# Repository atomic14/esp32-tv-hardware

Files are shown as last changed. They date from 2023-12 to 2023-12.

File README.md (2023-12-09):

# WIP - ESP32-TV Hardware Files

This is Work In Progress - I'm still working on this.

This repo contains/will contain the hardware design files for the ESP32-TV project.

## Schematic

You can either open this up in KiCad, or there's a PDF [here](./images/micro-esp32-s3.pdf).

Schematic

## PCB

Open this up in KiCad to export the Gerber files.

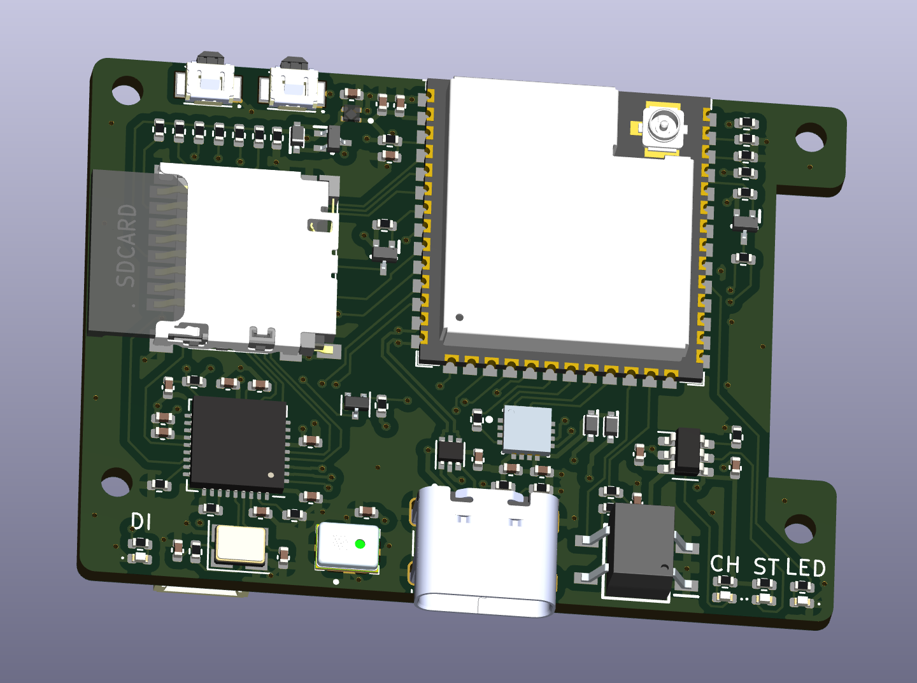
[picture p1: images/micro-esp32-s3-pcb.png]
PCB


## What's this all about?

More details to follow...

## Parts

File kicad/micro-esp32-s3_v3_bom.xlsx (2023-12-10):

Item # | *Designator | *Qty | Manufacturer | *Mfg Part # | Description / Value | *Package/Footprint | Mounting Type | Your Instructions / Notes
1 | R31,R30,R29,R28,R27,R26,R20,R13,R24,R19,R22,R23,R21 | 13 | KOA Speer | SG73P1EWTTP1002F | 10K | R_0402_1005Metric | SMD
2 | S2,S1 | 2 | Omron Electronics | B3U-3000P | B3U-3000P | SW_B3U-3000P | SMD
3 | C1,C20,C8,C10,C13,C11,C12,C21 | 8 | YAGEO | CC0402KRX5R6BB104 | 100nF | C_0402_1005Metric | SMD
4 | R3,R7,R4,R2 | 4 | RALEC | RTT02512JTH | 5.1K | R_0402_1005Metric | SMD
5 | U8 | 1 | OLEWOLFF | OWMMOD-403010A-S261F | OWMMOD-403010A-S261F | OWMMOD-403010A-S261F | SMD | NOTE - this is the top ported version - OWMMOD-403010A-S261F - https://mm.digikey.com/Volume0/opasdata/d220001/medias/docus/5395/OWMMOD-403010A-S261F.pdf
6 | C17,C19,C2,C16,C4 | 5 | CCTC | TCC0402X5R105K100AT | 1uF | C_0402_1005Metric | SMD
7 | U6 | 1 | TECH PUBLIC | USBLC6-2P6 | USBLC6-2P6 | SOT-666-6 | SMD
8 | D7,D6,D1 | 3 | Infineon | BAS 52-02V H6327 | BAS5202VH6327XTSA1 | SODFL1608X59N | SMD
9 | C5,C6,C18,C7 | 4 | SAMSUNG | CL05A106MP5NUNC | 10uF | C_0402_1005Metric | SMD
10 | R15 | 1 | YAGEO | AF0402FR-07634KL | 634K | R_0402_1005Metric | SMD
11 | IC1 | 1 | Everlight | IRM-H638T/TR2 | IRM-H638T/TR2 | SOP254P700X405-4N | SMD
12 | Q1,Q3,Q2 | 3 | onsemi | NTA4151PT1G | NTA4151PT1G | SOT50P160X90-3N | SMD
13 | U1 | 1 | onsemi | NCP167BMX330TBG | NCP167BMX330TBG | VREG_NCP167BMX330TBG | SMD
14 | R1,R14,R17 | 3 | KOA Speer | SG73P1EWTTP1003F | 100K | R_0402_1005Metric | SMD
15 | D5 | 1 | Everlight Elec | 16-213UYC/S530-A2/TR8 | YELLOW LED | LED_0402_1005Metric | SMD | Any 0402 Yellow LED
16 | R18 | 1 | KOA Speer | RK73H1ERTTP39R0F | 39 | R_0402_1005Metric | SMD
17 | R12,R10,R25 | 3 | KOA Speer | SG73P1EWTTP1202F | 12K | R_0402_1005Metric | SMD
18 | U4 | 1 | TOPPOWER | TP4057-42-SOT26-R | TP4057 | SOT-23-6 | SMD
19 | U2 | 1 | Espressif Systems | ESP32-S3-WROOM-1U-N8R8 | ESP32-S3-WROOM-1 | ESP32-S3-WROOM-1U | SMD
20 | Q4 | 1 | TECH PUBLIC | TPNTA4153NT1G | TPNTA4153NT1G | SOT-523-3 | SMD
21 | C3 | 1 | muRata | GRM155R60J226ME11D | 22uF | C_0402_1005Metric | SMD
22 | C14,C15 | 2 | Kyocera AVX | 0402ZK180FBWTR | 18pF | C_0402_1005Metric | SMD
23 | U5 | 1 | Microchip | USB2240-AEZG-06 | USB2240 | QFN-36-EP(6x6) | SMD
24 | R5,R9,R6,R8,R11 | 5 | KOA Speer | SG73P1EWTTP221G | 220R | R_0402_1005Metric | SMD
25 | Y1 | 1 | JWT | CF4024M00012 | Crystal_GND24 (24MHz) | Crystal_SMD_3225-4Pin_3.2x2.5mm | SMD
26 | C9 | 1 | Samsung Electro-Mechanics | CL05A475MP5NRNC | 4.7uF | C_0402_1005Metric | SMD
27 | J3 | 1 | Hirose | DM3D-SF | DM3D-SF | DM3DSF | SMD
28 | D2 | 1 | Everlight Elec | 16-213/R6C-AQ2R2B/3T | RED LED | LED_0402_1005Metric | SMD | Any 0402 Red LED
29 | D3 | 1 | Everlight Elec | 16-213/BHC-AN1P2/3T | BLUE LED | LED_0402_1005Metric | SMD | Any 0402 Blue LED
30 | R16 | 1 | KOA Speer | SG73P1EWTTP1004F | 1M | R_0402_1005Metric | SMD
31 | U3 | 1 | MAXIM | MAX98357AETE+T | MAX98357AETE+T | TQFN-16_L3.0-W3.0-P0.50-BL-EP1.5 | SMD
32 | J1 | 1 | 韩国韩荣 | TYPE-C-31-M-12 | TYPE-C-31-M-12 | USB-C_SMD-TYPE-C-31-M-12 | SMD
33 | D3 | 1 | Everlight Elec | 16-213/GHC-YR1S1/3T | GREEN LED | LED_0402_1005Metric | SMD | Any 0402 Green LED
34 | SPK1,BAT1 | 2 | JST | S2B-ZR-SM4A-TF | S2B-ZR-SM4A-TF_LF__SN_ | S2B-ZR-SM4A-TF | SMD
35 | QWIIC1 | 1 | JST | SM04B-SRSS-TB | SM04B-SRSS-TB_LF__SN_ | SM04B-SRSS-TB | SMD

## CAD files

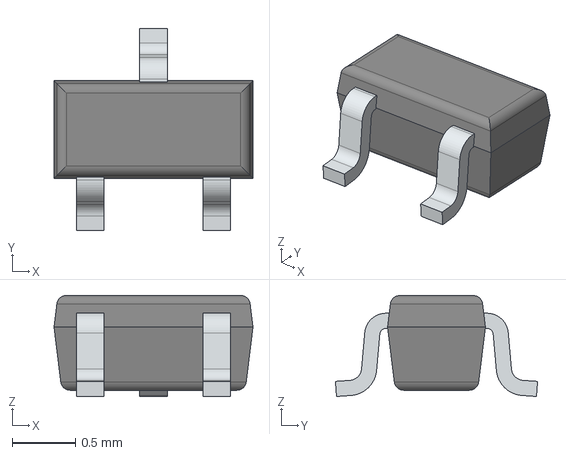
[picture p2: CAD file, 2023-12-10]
kicad/3dmodels/SOT-523-STP.stp
1.58 x 1.60 x 0.799 mm
LF
CPD

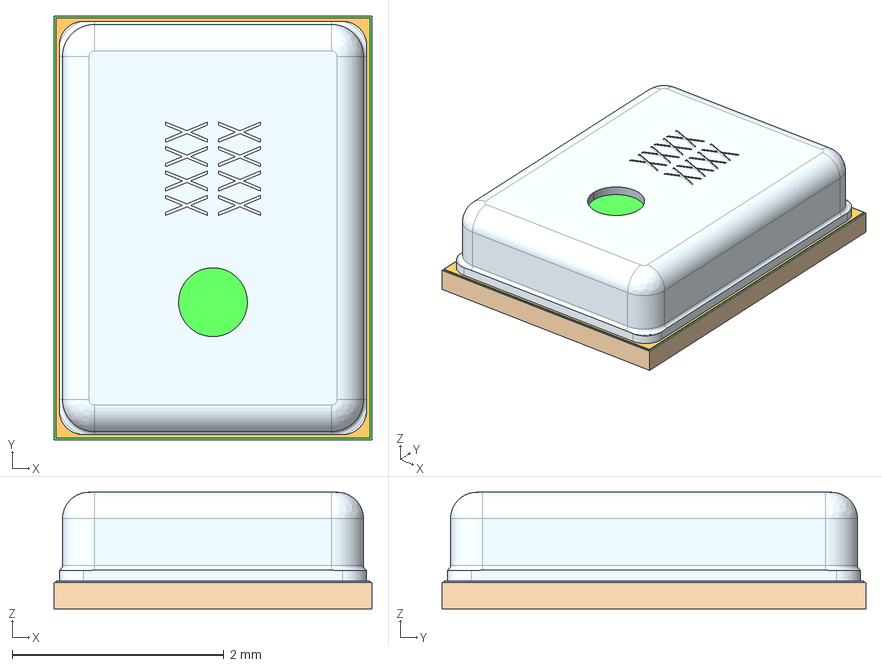
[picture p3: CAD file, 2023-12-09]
kicad/OWMMOD_403010A_S261F/OWMMOD-403010A-S261F.step
3.00 x 4.00 x 1.10 mm

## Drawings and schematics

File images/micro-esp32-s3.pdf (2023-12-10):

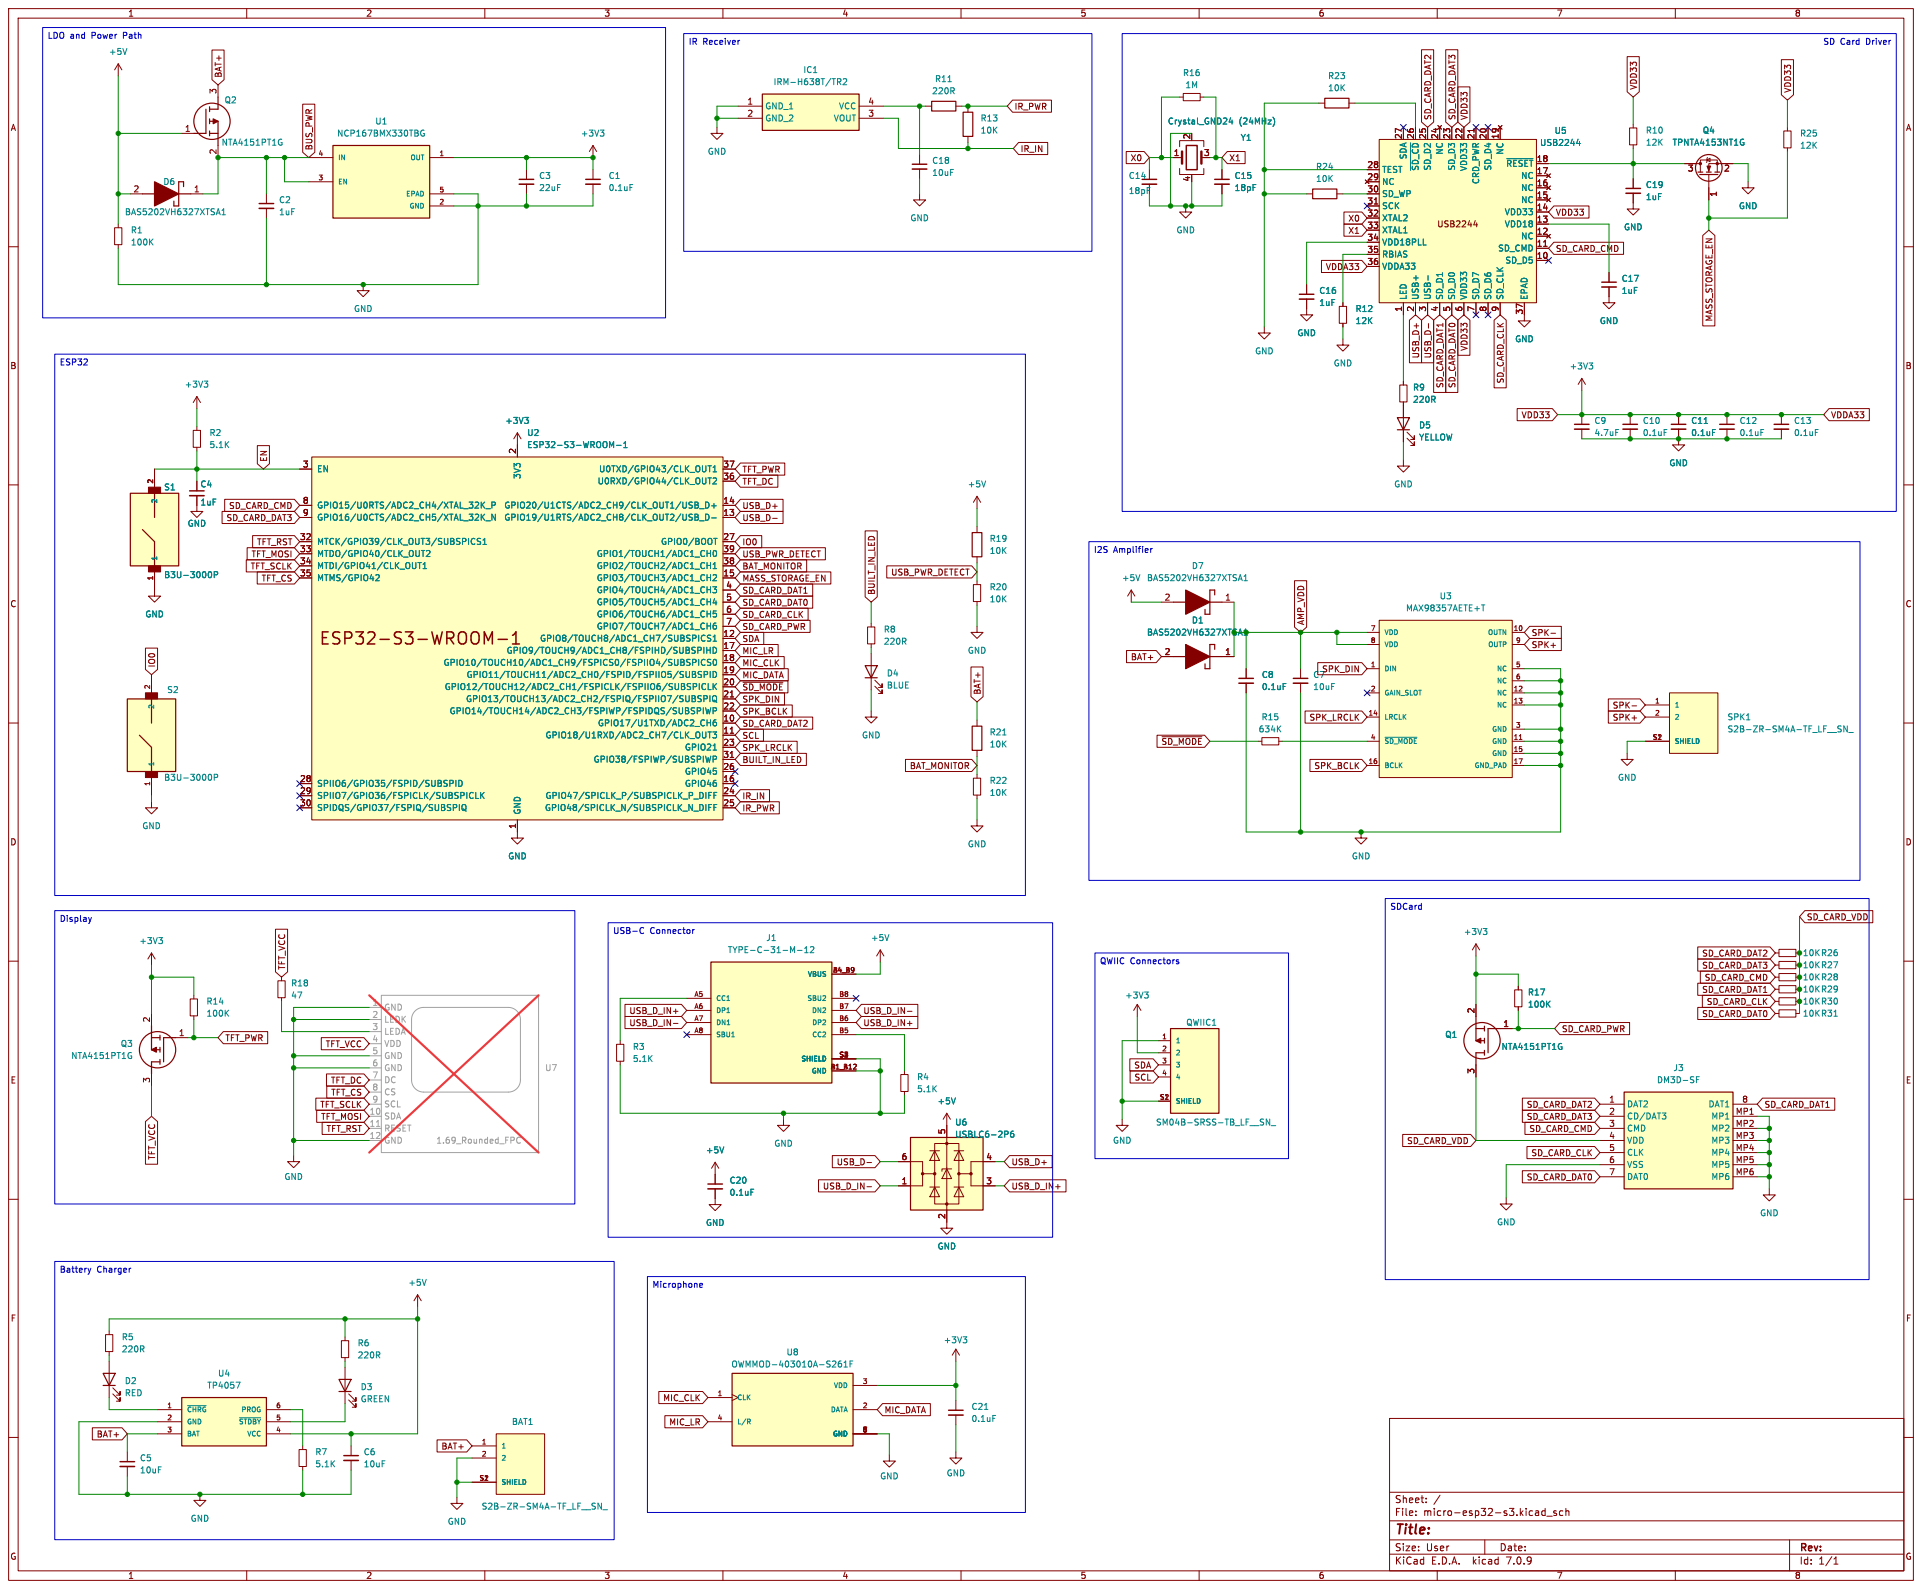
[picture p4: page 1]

LDO and Power Path

2 SD_D4 20 CRD_PWR 21 VDD33 22 SD_D3 23 NC 24 SD_D2 25 ~{SD_CD} 26 SDA 27 TEST 28 NC 29 USB- 3 SD_WP 30 SCK 31 XTAL2 32 XTAL1 33 VDD18PLL 34 RBIAS 35 VDDA33 36 SD_D1

1 SD_D5 10 SD_CMD 11 NC 12 VDD18 13 VDD33 14 NC 15 NC 16 NC 17 ~{RESET} 18 NC 19 USB+

2 GPIO12/TOUCH12/ADC2_CH1/FSPICLK/FSPIIO6/SUBSPICLK 20 GPIO13/TOUCH13/ADC2_CH2/FSPIQ/FSPIIO7/SUBSPIQ 21 GPIO14/TOUCH14/ADC2_CH3/FSPIWP/FSPIDQS/SUBSPIWP 22 GPIO21 23 GPIO47/SPICLK_P/SUBSPICLK_P_DIFF 24 GPIO48/SPICLK_N/SUBSPICLK_N_DIFF 25 GPIO45 26 GPIO0/BOOT 27 SPIIO6/GPIO35/FSPID/SUBSPID 28 SPIIO7/GPIO36/FSPICLK/SUBSPICLK 29 EN 3 SPIDQS/GPIO37/FSPIQ/SUBSPIQ 30 GPIO38/FSPIWP/SUBSPIWP 31 MTCK/GPIO39/CLK_OUT3/SUBSPICS1 32 MTDO/GPIO40/CLK_OUT2 33 MTDI/GPIO41/CLK_OUT1 34 MTMS/GPIO42 35 U0RXD/GPIO44/CLK_OUT2 36 U0TXD/GPIO43/CLK_OUT1 37 GPIO2/TOUCH2/ADC1_CH1 38 GPIO1/TOUCH1/ADC1_CH0 39 GPIO4/TOUCH4/ADC1_CH3 4 GPIO5/TOUCH5/ADC1_CH4 5 GPIO6/TOUCH6/ADC1_CH5 6 GPIO7/TOUCH7/ADC1_CH6 7 GPIO15/U0RTS/ADC2_CH4/XTAL_32K_P 8 GPIO16/U0CTS/ADC2_CH5/XTAL_32K_N 9 +3V3 S1B3U-3000P

2 GPIO12/TOUCH12/ADC2_CH1/FSPICLK/FSPIIO6/SUBSPICLK 20 GPIO13/TOUCH13/ADC2_CH2/FSPIQ/FSPIIO7/SUBSPIQ 21 GPIO14/TOUCH14/ADC2_CH3/FSPIWP/FSPIDQS/SUBSPIWP 22 GPIO21 23 GPIO47/SPICLK_P/SUBSPICLK_P_DIFF 24 GPIO48/SPICLK_N/SUBSPICLK_N_DIFF 25 GPIO45 26 GPIO0/BOOT 27 SPIIO6/GPIO35/FSPID/SUBSPID 28 SPIIO7/GPIO36/FSPICLK/SUBSPICLK 29 EN 3 SPIDQS/GPIO37/FSPIQ/SUBSPIQ 30 GPIO38/FSPIWP/SUBSPIWP 31 MTCK/GPIO39/CLK_OUT3/SUBSPICS1 32 MTDO/GPIO40/CLK_OUT2 33 MTDI/GPIO41/CLK_OUT1 34 MTMS/GPIO42 35 U0RXD/GPIO44/CLK_OUT2 36 U0TXD/GPIO43/CLK_OUT1 37 GPIO2/TOUCH2/ADC1_CH1 38 GPIO1/TOUCH1/ADC1_CH0 39 GPIO4/TOUCH4/ADC1_CH3 4 GPIO5/TOUCH5/ADC1_CH4 5 GPIO6/TOUCH6/ADC1_CH5 6 GPIO7/TOUCH7/ADC1_CH6 7 GPIO15/U0RTS/ADC2_CH4/XTAL_32K_P 8 GPIO16/U0CTS/ADC2_CH5/XTAL_32K_N 9 U2ESP32-S3-WROOM-1

1 GPIO17/U1TXD/ADC2_CH6 10 GPIO18/U1RXD/ADC2_CH7/CLK_OUT3 11 GPIO8/TOUCH8/ADC1_CH7/SUBSPICS1 12 GPIO19/U1RTS/ADC2_CH8/CLK_OUT2/USB_D- 13 GPIO20/U1CTS/ADC2_CH9/CLK_OUT1/USB_D+ 14 GPIO3/TOUCH3/ADC1_CH2 15 GPIO46 16 GPIO9/TOUCH9/ADC1_CH8/FSPIHD/SUBSPIHD 17 GPIO10/TOUCH10/ADC1_CH9/FSPICS0/FSPIIO4/SUBSPICS0 18 GPIO11/TOUCH11/ADC2_CH0/FSPID/FSPIIO5/SUBSPID 19 3V3

Id: 1/1 Title: File: micro-esp32-s3.kicad_sch Sheet: /

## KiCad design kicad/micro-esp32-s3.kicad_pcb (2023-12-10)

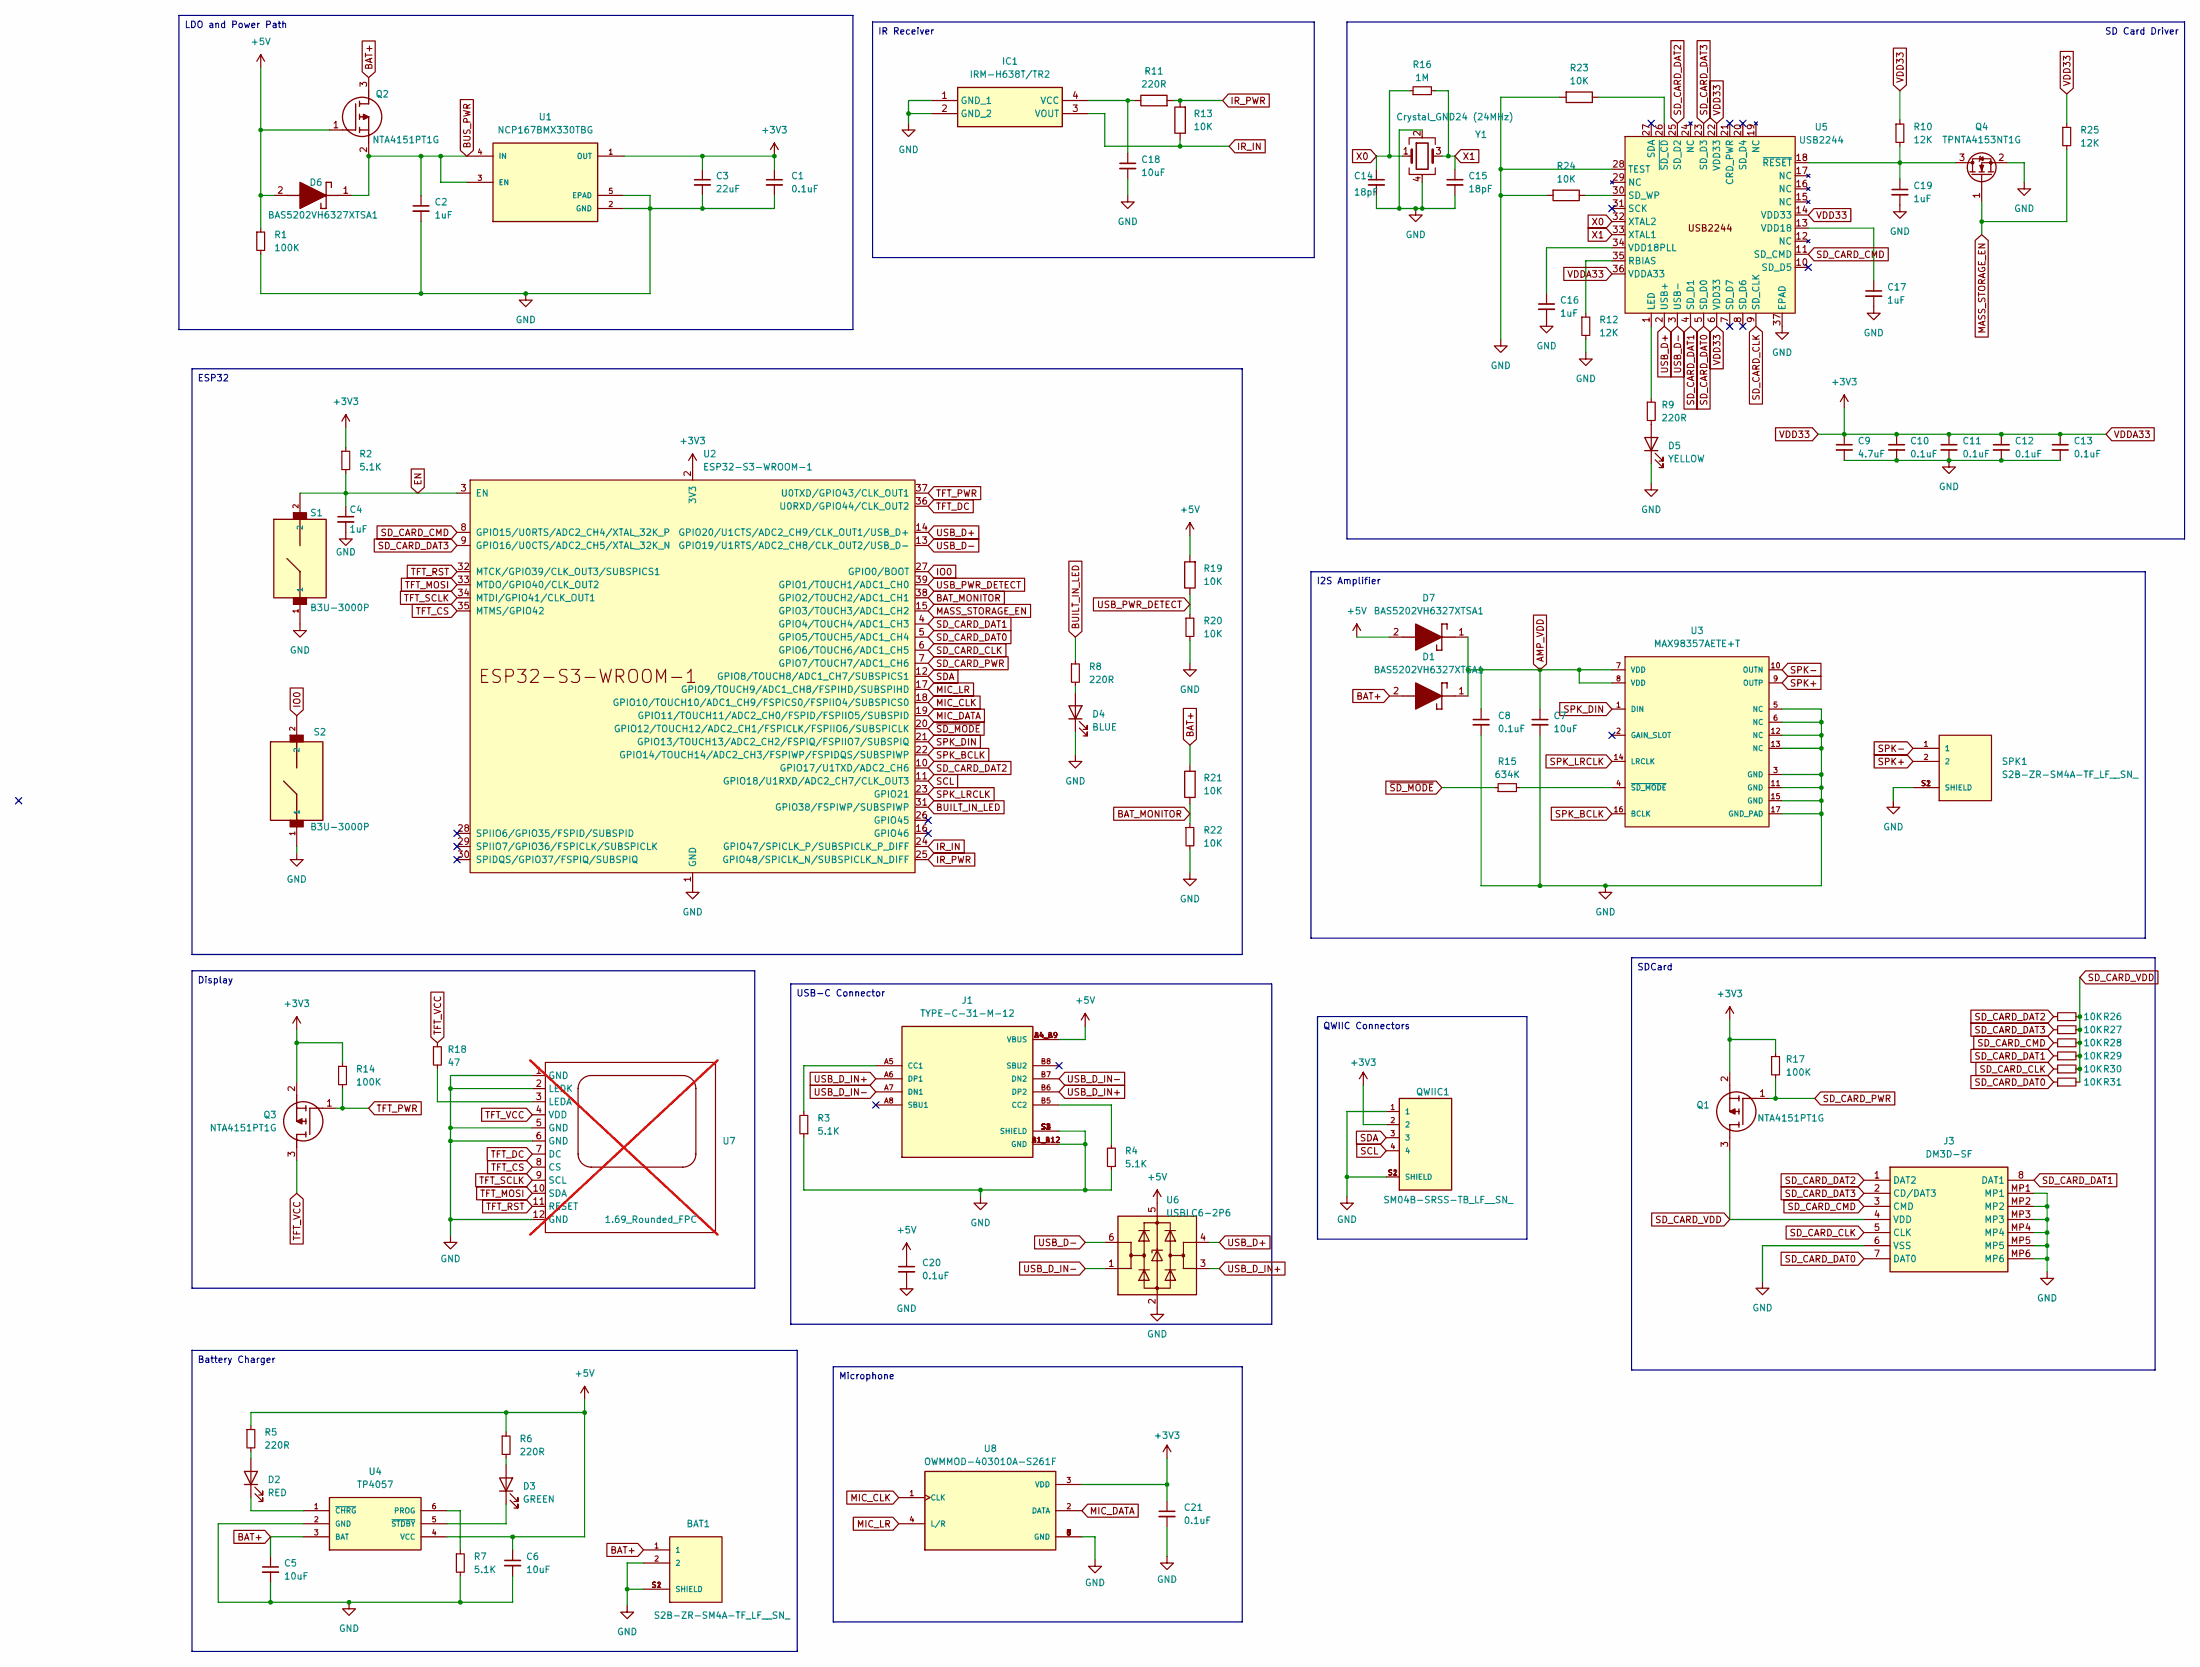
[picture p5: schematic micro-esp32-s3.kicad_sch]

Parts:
BAT1: S2B-ZR-SM4A-TF_LF__SN_; JST_S2B-ZR-SM4A-TF_LF__SN_; PARTREV N/A
C1, C8, C10, C11, C12, C13, C20, C21: 0.1uF; C_0402_1005Metric
C2: 1uF; C_0402_1005Metric; Mfg Part # test
C3: 22uF; C_0402_1005Metric
C4, C16, C17, C19: 1uF; C_0402_1005Metric
C5, C6, C7, C18: 10uF; C_0402_1005Metric
C9: 4.7uF; C_0402_1005Metric
C14, C15: 18pF; C_0402_1005Metric
D1, D6, D7: BAS5202VH6327XTSA1; SODFL1608X59N; Manufacturer_Part_Number BAS5202VH6327XTSA1; Mouser Part Number 726-BAS5202VH6327XTS
D2: RED; LED_0402_1005Metric
D3: GREEN; LED_0402_1005Metric
D4: BLUE; LED_0402_1005Metric
D5: YELLOW; LED_0402_1005Metric
IC1: IRM-H638T/TR2; SOP254P700X405-4N; Manufacturer_Part_Number IRM-H638M3/TR2
J1: TYPE-C-31-M-12; HRO_TYPE-C-31-M-12; PARTREV 2020.12.08
J3: DM3D-SF; DM3DSF; Manufacturer_Part_Number DM3D-SF; Mouser Part Number 798-DM3D-SF
Q1, Q2, Q3: NTA4151PT1G; SOT50P160X90-3N; Manufacturer_Part_Number NTA4151PT1G; Mouser Part Number 863-NTA4151PT1G
Q4: TPNTA4153NT1G; SOT-523
QWIIC1: SM04B-SRSS-TB_LF__SN_; JST_SM04B-SRSS-TB_LF__SN_
R1, R14, R17: 100K; R_0402_1005Metric
R2, R3, R4, R7: 5.1K; R_0402_1005Metric
R5, R6, R8, R9, R11: 220R; R_0402_1005Metric
R10, R12, R25: 12K; R_0402_1005Metric
R13, R19, R20, R21, R22, R23, R24, R26, R27, R28, R29, R30, R31: 10K; R_0402_1005Metric
R15: 634K; R_0402_1005Metric
R16: 1M; R_0402_1005Metric
R18: 47; R_0402_1005Metric
S1, S2: B3U-3000P; SW_B3U-3000P
SPK1: S2B-ZR-SM4A-TF_LF__SN_; JST_S2B-ZR-SM4A-TF_LF__SN_; PARTREV N/A
U1: NCP167BMX330TBG; VREG_NCP167BMX330TBG; PARTREV 5
U2: ESP32-S3-WROOM-1; ESP32-S3-WROOM-1U
U3: MAX98357AETE+T; Maxim_Electronics-21-0896-0-0-0; mouser part number 700-MAX98357AETE+T; digikey description Amplifier IC 2-Channel (Stereo) Class D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
U4: TP4057; SOT-23-6
U5: USB2244; QFN-36-1EP_6x6mm_P0.5mm_EP4.1x4.1mm
U6: USBLC6-2P6; SOT-666
U7: 1.69_Rounded_FPC; fpc_12_pin_0.7_pitch; not fitted
U8: OWMMOD-403010A-S261F; MIC_OWMMOD-403010A-S261F; PARTREV 00; DigiKey_Part_Number 3949-OWMMOD-403010A-S261F-ND
Y1: Crystal_GND24 (24MHz); Crystal_SMD_3225-4Pin_3.2x2.5mm

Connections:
+5V: C6.1, C20.1, D6.2 (A), D7.2 (A), J1.A4_B9 (VBUS), J1.B4_A9 (VBUS), Q2.1 (G), R1.1, R5.1, R6.1, R19.2, U4.4 (VCC), U6.5 (VBUS)
AMP_VDD: C7.1, C8.1, D1.1 (K), D7.1 (K), U3.7 (VDD), U3.8 (VDD)
BAT+: BAT1.1, C5.1, D1.2 (A), Q2.3 (D), R21.2, U4.3 (BAT)
BAT_MONITOR: R21.1, R22.1, U2.38 (GPIO2/TOUCH2/ADC1_CH1)
BUILT_IN_LED: R8.1, U2.31 (GPIO38/FSPIWP/SUBSPIWP)
BUS_PWR: C2.1, D6.1 (K), Q2.2 (S), U1.3 (EN), U1.4 (IN)
EN: C4.1, R2.2, S1.2, U2.3 (EN)
GND: BAT1.2, BAT1.S1 (SHIELD), BAT1.S2 (SHIELD), C1.2, C2.2, C3.2, C4.2, C5.2, C6.2, C7.2, C8.2, C9.2, C10.2, C11.2, C12.2, C13.2, C14.2, C15.2, C16.2, C17.2, C18.2, C19.2, C20.2, C21.2, D4.1 (K), D5.1 (K), IC1.1 (GND_1), IC1.2 (GND_2), J1.A1_B12 (GND), J1.B1_A12 (GND), J1.S1 (SHIELD), J1.S2 (SHIELD), J1.S3 (SHIELD), J1.S4 (SHIELD), J3.6 (VSS), J3.MP1, J3.MP2, J3.MP3, J3.MP4, J3.MP5, J3.MP6, Q4.2 (S), QWIIC1.1, QWIIC1.S1 (SHIELD), QWIIC1.S2 (SHIELD), R1.2, R3.1, R4.1, R7.2, R12.2, R20.2, R22.2, R23.2, R24.2, S1.1, S2.1, SPK1.S1 (SHIELD), SPK1.S2 (SHIELD), U1.2 (GND), U1.5 (EPAD), U2.1 (GND), U2.40 (GND), U2.41 (GND), U3.3 (GND), U3.5 (NC), U3.6 (NC), U3.11 (GND), U3.12 (NC), U3.13 (NC), U3.15 (GND), U3.17 (GND_PAD), U4.2 (GND), U5.28 (TEST), U5.37 (EPAD), U6.2 (GND), U7.1 (GND), U7.2 (LEDK), U7.5 (GND), U7.6 (GND), U7.12 (GND), U8.5 (GND), U8.6 (GND), U8.7 (GND), U8.8 (GND), Y1.2, Y1.4
IO0: S2.2, U2.27 (GPIO0/BOOT)
IR_IN: IC1.3 (VOUT), R13.1, U2.24 (GPIO47/SPICLK_P/SUBSPICLK_P_DIFF)
IR_PWR: R11.2, R13.2, U2.25 (GPIO48/SPICLK_N/SUBSPICLK_N_DIFF)
MASS_STORAGE_EN: Q4.1 (G), R25.2, U2.15 (GPIO3/TOUCH3/ADC1_CH2)
MIC_CLK: U2.18 (GPIO10/TOUCH10/ADC1_CH9/FSPICS0/FSPIIO4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), U8.1 (CLK)
MIC_DATA: U2.19 (GPIO11/TOUCH11/ADC2_CH0/FSPID/FSPIIO5/S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), U8.2 (DATA)
MIC_LR: U2.17 (GPIO9/TOUCH9/ADC1_CH8/FSPIHD/SUBSPIHD), U8.4 (L/R)
unnamed: D2.2 (A), R5.2
unnamed: D2.1 (K), U4.1 (~CHRG)
unnamed: D3.2 (A), R6.2
unnamed: D3.1 (K), U4.5 (~STDBY)
unnamed: D4.2 (A), R8.2
unnamed: D5.2 (A), R9.2
unnamed: C18.1, IC1.4 (VCC), R11.1
unnamed: J1.A5 (CC1), R3.2
unnamed: J1.B5 (CC2), R4.2
unnamed: C19.1, Q4.3 (D), R10.2, U5.18 (~RESET)
unnamed: R15.2, U3.4 (~SD_MODE)
unnamed: R7.1, U4.6 (PROG)
unnamed: R9.1, U5.1 (LED)
unnamed: R12.1, U5.35 (RBIAS)
unnamed: R24.1, U5.30 (SD_WP)
unnamed: C17.1, U5.13 (VDD18)
unnamed: C16.1, U5.34 (VDD18PLL)
unnamed: R23.1, U5.26 (~SD_CD)
unnamed: R18.2, U7.3 (LEDA)
SCL: QWIIC1.4, U2.11 (GPIO18/U1RXD/ADC2_CH7/CLK_OUT3)
SDA: QWIIC1.3, U2.12 (GPIO8/TOUCH8/ADC1_CH7/SUBSPICS1)
SD_CARD_CLK: J3.5 (CLK), R30.1, U2.6 (GPIO6/TOUCH6/ADC1_CH5), U5.9 (SD_CLK)
SD_CARD_CMD: J3.3 (CMD), R28.1, U2.8 (GPIO15/U0RTS/ADC2_CH4/XTAL_32K_P), U5.11 (SD_CMD)
SD_CARD_DAT0: J3.7 (DAT0), R31.1, U2.5 (GPIO5/TOUCH5/ADC1_CH4), U5.5 (SD_D0)
SD_CARD_DAT1: J3.8 (DAT1), R29.1, U2.4 (GPIO4/TOUCH4/ADC1_CH3), U5.4 (SD_D1)
SD_CARD_DAT2: J3.1 (DAT2), R26.1, U2.10 (GPIO17/U1TXD/ADC2_CH6), U5.25 (SD_D2)
SD_CARD_DAT3: J3.2 (CD/DAT3), R27.1, U2.9 (GPIO16/U0CTS/ADC2_CH5/XTAL_32K_N), U5.23 (SD_D3)
SD_CARD_PWR: Q1.1 (G), R17.2, U2.7 (GPIO7/TOUCH7/ADC1_CH6)
SD_CARD_VDD: J3.4 (VDD), Q1.3 (D), R26.2, R27.2, R28.2, R29.2, R30.2, R31.2
SPK+: SPK1.2, U3.9 (OUTP)
SPK-: SPK1.1, U3.10 (OUTN)
SPK_BCLK: U2.22 (GPIO14/TOUCH14/ADC2_CH3/FSPIWP/FSPIDQS/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), U3.16 (BCLK)
SPK_DIN: U2.21 (GPIO13/TOUCH13/ADC2_CH2/FSPIQ/FSPIIO7/S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), U3.1 (DIN)
SPK_LRCLK: U2.23 (GPIO21), U3.14 (LRCLK)
TFT_CS: U2.35 (MTMS/GPIO42), U7.8 (CS)
TFT_DC: U2.36 (U0RXD/GPIO44/CLK_OUT2), U7.7 (DC)
TFT_MOSI: U2.33 (MTDO/GPIO40/CLK_OUT2), U7.10 (SDA)
TFT_PWR: Q3.1 (G), R14.2, U2.37 (U0TXD/GPIO43/CLK_OUT1)
TFT_RST: U2.32 (MTCK/GPIO39/CLK_OUT3/SUBSPICS1), U7.11 (RESET)
TFT_SCLK: U2.34 (MTDI/GPIO41/CLK_OUT1), U7.9 (SCL)
TFT_VCC: Q3.3 (D), R18.1, U7.4 (VDD)
USB_D+: U2.14 (GPIO20/U1CTS/ADC2_CH9/CLK_OUT1/USB_D+), U5.2 (USB+), U6.4 (I/O2)
USB_D-: U2.13 (GPIO19/U1RTS/ADC2_CH8/CLK_OUT2/USB_D-), U5.3 (USB-), U6.6 (I/O1)
USB_D_IN+: J1.A6 (DP1), J1.B6 (DP2), U6.3 (I/O2)
USB_D_IN-: J1.A7 (DN1), J1.B7 (DN2), U6.1 (I/O1)
USB_PWR_DETECT: R19.1, R20.1, U2.39 (GPIO1/TOUCH1/ADC1_CH0)
VDD33: C1.1, C3.1, C9.1, C10.1, C11.1, C12.1, C13.1, C21.1, Q1.2 (S), Q3.2 (S), QWIIC1.2, R2.1, R10.1, R14.1, R17.1, R25.1, U1.1 (OUT), U2.2 (3V3), U5.6 (VDD33), U5.14 (VDD33), U5.22 (VDD33), U5.36 (VDDA33), U8.3 (VDD)
X0: C14.1, R16.1, U5.32 (XTAL2), Y1.1
X1: C15.1, R16.2, U5.33 (XTAL1), Y1.3
~SD_MODE: R15.1, U2.20 (GPIO12/TOUCH12/ADC2_CH1/FSPICLK/FSPIIO6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)

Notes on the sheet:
QWIIC Connectors
Microphone
SDCard
Battery Charger
SD Card Driver
IR Receiver
ESP32
Display
USB-C Connector
I2S Amplifier
LDO and Power Path

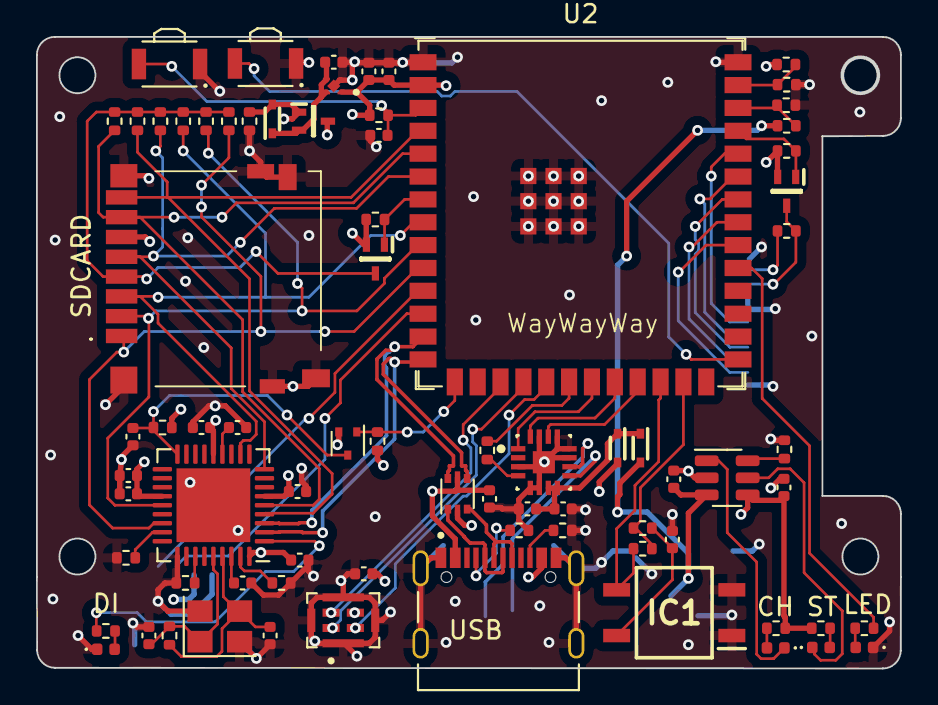
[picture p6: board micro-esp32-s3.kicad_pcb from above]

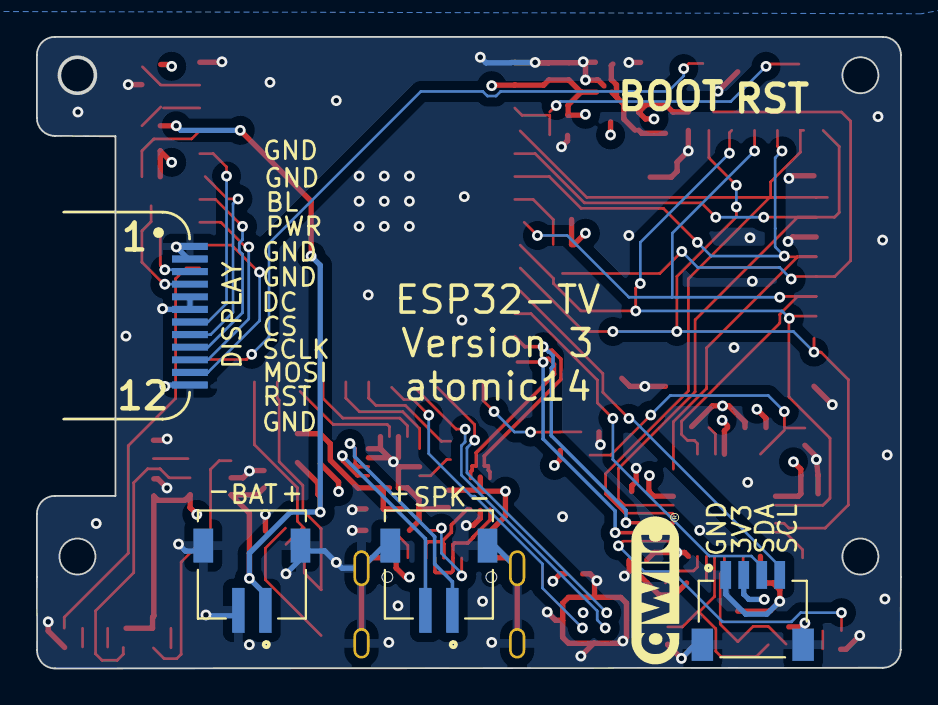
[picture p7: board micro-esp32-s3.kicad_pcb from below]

Board: 4 copper layers, 48.0 x 35.1 mm, 80 parts (4 on the bottom side), 65 nets.

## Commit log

2023-11-14 Change pull down resistor on mass storage enable to 1K
    [micro-esp32-s3.kicad_sch]
2023-11-17 Clean up schematic
    [micro-esp32-s3.kicad_sch]
2023-11-17 Fix power path in schematic
    [micro-esp32-s3.kicad_sch]
2023-11-17 Fix diode position
    [micro-esp32-s3.kicad_pcb]
2023-11-17 Update PCB screenshot
2023-12-04 Make sure GPIO45 and GPIO46 are disconnected
    [micro-esp32-s3.kicad_sch]
2023-12-08 WIP - version 3
    [micro-esp32-s3.kicad_pcb, micro-esp32-s3.kicad_sch]
2023-12-08 V3 Work in progress
    [micro-esp32-s3.kicad_pcb, micro-esp32-s3.kicad_sch]
2023-12-09 Version 3 - Ready for review
    [OWMMOD-403010A-S261F.step, micro-esp32-s3.kicad_pcb, micro-esp32-s3.kicad_sch]
2023-12-10 Submitted Version
    [SOT-523-STP.stp, micro-esp32-s3.kicad_pcb, micro-esp32-s3.kicad_sch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]
